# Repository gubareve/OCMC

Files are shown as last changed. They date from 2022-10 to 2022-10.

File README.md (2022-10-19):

# Open-source Custom Mechanical Keyboard

OCMC is a custom PCB running on the ATMEGA328P chipset.
Designed using KiCAD 6.0 and assembled using JLCPCB.






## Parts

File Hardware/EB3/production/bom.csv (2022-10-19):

Designator | Footprint | Quantity | Value | LCSC Part #
J2 | USB_C_Receptacle_XKB_U262-16XN-4BVC11 | 1 | USB_C_Receptacle
Y1 | Crystal_SMD_3225-4Pin_3.2x2.5mm | 1 | 16MHz | C13738
D1 | LED_0805_2012Metric | 1 | LED | C84256
C5 | C_0805_2012Metric | 1 | 10uF | C17024
JP3 | SolderJumper-2_P1.3mm_Open_RoundedPad1.0x1.5mm | 1 | SolderJumper_2_Open
J4 | PinSocket_1x03_P2.54mm_Vertical | 1 | Power Connectors
J3 | PinSocket_1x06_P2.54mm_Vertical | 1 | Programming Connectors
C2 | C_0805_2012Metric | 1 | 10uF | C17024
DS1 | WC1602A | 1 | WC1602A
SW3 | SW_Cherry_MX_Plate_1.00u | 1 | CONTROL
SW15 | SW_Cherry_MX_Plate_1.00u | 1 | 6
SW9 | SW_Cherry_MX_Plate_1.00u | 1 | 8
SW5 | SW_Cherry_MX_Plate_1.00u | 1 | 4
U1 | DIP-28_W7.62mm | 1 | ATmega328-P
JP5 | SolderJumper-2_P1.3mm_Open_RoundedPad1.0x1.5mm | 1 | SolderJumper_2_Open
RV1 | Potentiometer_Piher_PT-6-V_Vertical_Hole | 1 | 10k
R3 | R_0805_2012Metric | 1 | 10k | C17414
SW10 | SW_Cherry_MX_Plate_1.00u | 1 | 5
SW7 | SW_Cherry_MX_Plate_1.00u | 1 | ENTER
C3 | C_0805_2012Metric | 1 | 10uF | C17024
JP2 | TestPoint_2Pads_Pitch2.54mm_Drill0.8mm | 1 | 9-12v
SW12 | SW_Cherry_MX_Plate_1.00u | 1 | 0
SW19 | SW_Cherry_MX_Plate_1.00u | 1 | MULT
SW13 | SW_Cherry_MX_Plate_1.00u | 1 | DEL
JP4 | TestPoint_2Pads_Pitch2.54mm_Drill0.8mm | 1 | RESET
C4 | C_0805_2012Metric | 1 | 0.1uF | C49678
SW21 | SW_Cherry_MX_Plate_1.00u | 1 | SUB
J1 | BarrelJack_GCT_DCJ200-10-A_Horizontal | 1 | Barrel_Jack
SW20 | SW_Cherry_MX_Plate_1.00u | 1 | DIV
SW8 | SW_Cherry_MX_Plate_1.00u | 1 | ALT
C7 | C_0805_2012Metric | 1 | 100n | C49678
C6 | C_0805_2012Metric | 1 | 22pf | C1804
SW11 | SW_Cherry_MX_Plate_1.00u | 1 | 2
J5 | PinSocket_1x04_P2.54mm_Vertical | 1 | SPI Connectors
SW16 | SW_Cherry_MX_Plate_1.00u | 1 | 3
C1 | C_0805_2012Metric | 1 | 22pf | C1804
SW18 | SW_Cherry_MX_Plate_1.00u | 1 | CLR
SW4 | SW_Cherry_MX_Plate_1.00u | 1 | 7
SW6 | SW_Cherry_MX_Plate_1.00u | 1 | 1
SW1 | SW_Push_2P2T_Toggle_CK_PVA2OAH5xxxxxxV2 | 1 | SW_SPST
SW22 | SW_Cherry_MX_Plate_1.00u | 1 | ADD
R1 | R_0805_2012Metric | 1 | 50
SW17 | SW_Cherry_MX_Plate_1.00u | 1 | DOT
U2 | TO-92_Inline | 1 | L78L05_TO92
SW14 | SW_Cherry_MX_Plate_1.00u | 1 | 9
JP1 | TestPoint_2Pads_Pitch2.54mm_Drill0.8mm | 1 | 5v
R2 | R_0805_2012Metric | 1 | 220 | C17520

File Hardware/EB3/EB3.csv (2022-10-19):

Id | Designator | Package | Quantity | Designation | Supplier and ref
1 | J2 | USB_Micro-B_Amphenol_10118194_Horizontal | 1 | USB_B_Micro
2 | SW1 | SW_Push_2P2T_Toggle_CK_PVA2OAH5xxxxxxV2 | 1 | SW_SPST
3 | Y1 | C_1210_3225Metric | 1 | 16MHz
4 | U2 | TO-92_Inline | 1 | L78L05_TO92
5 | U1 | DIP-28_W7.62mm | 1 | ATmega328-P
6 | RV1 | Potentiometer_Piher_PT-6-V_Vertical_Hole | 1 | 10k
7 | R3 | R_0805_2012Metric | 1 | 10k
8 | R2 | R_0805_2012Metric | 1 | 220
9 | R1 | R_0805_2012Metric | 1 | 200
10 | JP5,JP3 | SolderJumper-2_P1.3mm_Open_RoundedPad1.0x1.5mm | 2 | SolderJumper_2_Open
11 | JP4 | TestPoint_2Pads_Pitch2.54mm_Drill0.8mm | 1 | RESET
12 | JP2 | TestPoint_2Pads_Pitch2.54mm_Drill0.8mm | 1 | 9-12v
13 | JP1 | TestPoint_2Pads_Pitch2.54mm_Drill0.8mm | 1 | 5v
14 | J5 | PinSocket_1x04_P2.54mm_Vertical | 1 | SPI Connectors
15 | J4 | PinSocket_1x03_P2.54mm_Vertical | 1 | Power Connectors
16 | J3 | PinSocket_1x06_P2.54mm_Vertical | 1 | Programming Connectors
17 | J1 | BarrelJack_GCT_DCJ200-10-A_Horizontal | 1 | Barrel_Jack
18 | D1 | LED_0805_2012Metric | 1 | LED
19 | C7 | C_0805_2012Metric | 1 | 100n
20 | C6,C1 | C_0805_2012Metric | 2 | 22pf
21 | C5,C3,C2 | C_0805_2012Metric | 3 | 10uF
22 | C4 | C_0805_2012Metric | 1 | 0.1uF
23 | DS1 | WC1602A | 1 | WC1602A
24 | SW3 | SW_Cherry_MX_Plate_1.00u | 1 | CONTROL
25 | SW15 | SW_Cherry_MX_Plate_1.00u | 1 | 6
26 | SW9 | SW_Cherry_MX_Plate_1.00u | 1 | 8
27 | SW5 | SW_Cherry_MX_Plate_1.00u | 1 | 4
28 | SW10 | SW_Cherry_MX_Plate_1.00u | 1 | 5
29 | SW7 | SW_Cherry_MX_Plate_1.00u | 1 | ENTER
30 | SW12 | SW_Cherry_MX_Plate_1.00u | 1 | 0
31 | SW19 | SW_Cherry_MX_Plate_1.00u | 1 | MULT
32 | SW13 | SW_Cherry_MX_Plate_1.00u | 1 | DEL
33 | SW21 | SW_Cherry_MX_Plate_1.00u | 1 | SUB
34 | SW20 | SW_Cherry_MX_Plate_1.00u | 1 | DIV
35 | SW8 | SW_Cherry_MX_Plate_1.00u | 1 | ALT
36 | SW11 | SW_Cherry_MX_Plate_1.00u | 1 | 2
37 | SW16 | SW_Cherry_MX_Plate_1.00u | 1 | 3
38 | SW18 | SW_Cherry_MX_Plate_1.00u | 1 | CLR
39 | SW4 | SW_Cherry_MX_Plate_1.00u | 1 | 7
40 | SW6 | SW_Cherry_MX_Plate_1.00u | 1 | 1
41 | SW22 | SW_Cherry_MX_Plate_1.00u | 1 | ADD
42 | SW17 | SW_Cherry_MX_Plate_1.00u | 1 | DOT
43 | SW14 | SW_Cherry_MX_Plate_1.00u | 1 | 9

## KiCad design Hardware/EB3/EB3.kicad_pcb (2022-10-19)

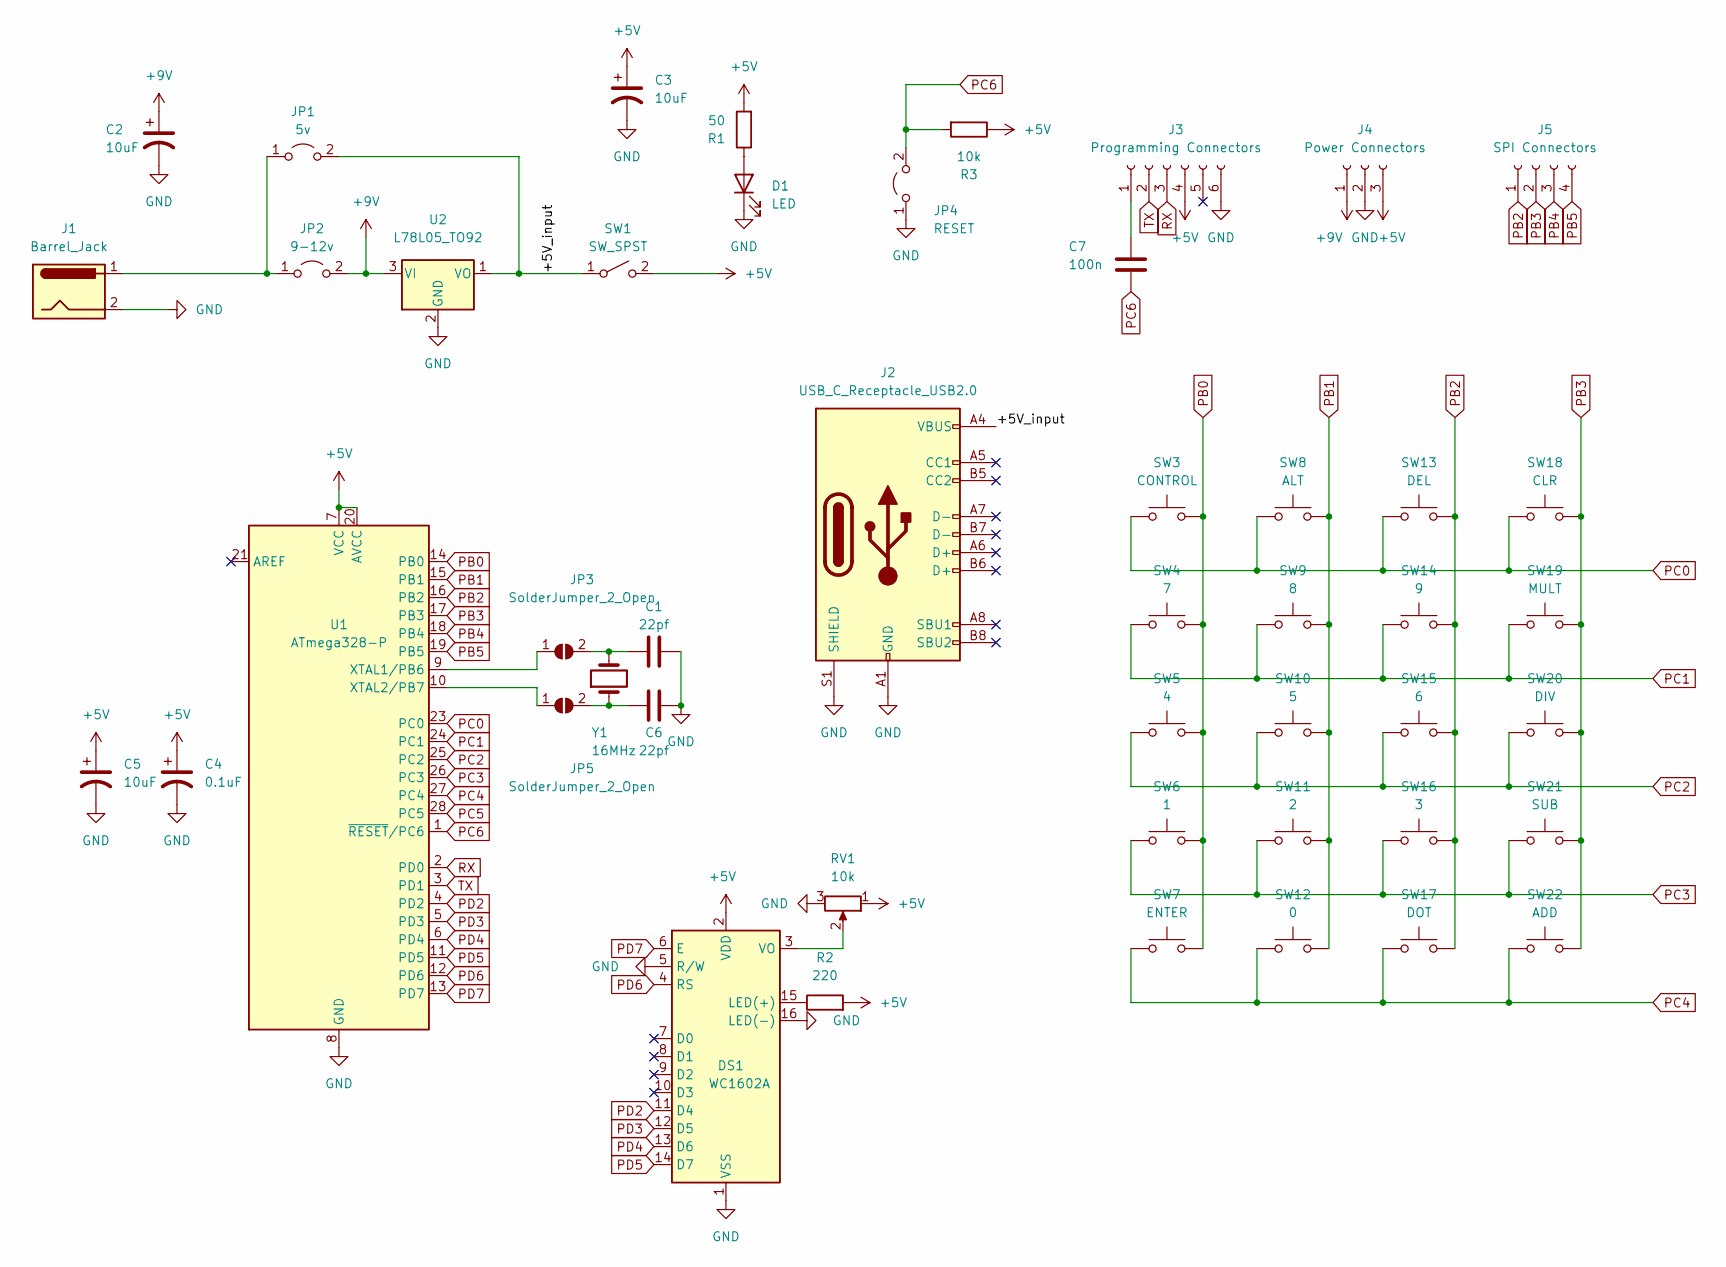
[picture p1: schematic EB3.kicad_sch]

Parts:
C1, C6: 22pf; C_0805_2012Metric; LCSC C1804
C2, C3, C5: 10uF; C_0805_2012Metric; LCSC C17024
C4: 0.1uF; C_0805_2012Metric; LCSC C49678
C7: 100n; C_0805_2012Metric; LCSC C49678
D1: LED; LED_0805_2012Metric; LCSC C84256
DS1: WC1602A
J1: Barrel_Jack; BarrelJack_GCT_DCJ200-10-A_Horizontal
J2: USB_C_Receptacle_USB2.0
J3: Programming Connectors; PinSocket_1x06_P2.54mm_Vertical
J4: Power Connectors; PinSocket_1x03_P2.54mm_Vertical
J5: SPI Connectors; PinSocket_1x04_P2.54mm_Vertical
JP1: 5v; TestPoint_2Pads_Pitch2.54mm_Drill0.8mm
JP2: 9-12v; TestPoint_2Pads_Pitch2.54mm_Drill0.8mm
JP3, JP5: SolderJumper_2_Open; SolderJumper-2_P1.3mm_Open_RoundedPad1.0x1.5mm
JP4: RESET; TestPoint_2Pads_Pitch2.54mm_Drill0.8mm
R1: 50; R_0805_2012Metric; LCSC C23182
R2: 220; R_0805_2012Metric; LCSC C17520
R3: 10k; R_0805_2012Metric; LCSC C17414
RV1: 10k; Potentiometer_Piher_PT-6-V_Vertical_Hole
SW1: SW_SPST; SW_Push_2P2T_Toggle_CK_PVA2OAH5xxxxxxV2
SW3: CONTROL; SW_Cherry_MX_Plate_1.00u
SW4: 7; SW_Cherry_MX_Plate_1.00u
SW5: 4; SW_Cherry_MX_Plate_1.00u
SW6: 1; SW_Cherry_MX_Plate_1.00u
SW7: ENTER; SW_Cherry_MX_Plate_1.00u
SW8: ALT; SW_Cherry_MX_Plate_1.00u
SW9: 8; SW_Cherry_MX_Plate_1.00u
SW10: 5; SW_Cherry_MX_Plate_1.00u
SW11: 2; SW_Cherry_MX_Plate_1.00u
SW12: 0; SW_Cherry_MX_Plate_1.00u
SW13: DEL; SW_Cherry_MX_Plate_1.00u
SW14: 9; SW_Cherry_MX_Plate_1.00u
SW15: 6; SW_Cherry_MX_Plate_1.00u
SW16: 3; SW_Cherry_MX_Plate_1.00u
SW17: DOT; SW_Cherry_MX_Plate_1.00u
SW18: CLR; SW_Cherry_MX_Plate_1.00u
SW19: MULT; SW_Cherry_MX_Plate_1.00u
SW20: DIV; SW_Cherry_MX_Plate_1.00u
SW21: SUB; SW_Cherry_MX_Plate_1.00u
SW22: ADD; SW_Cherry_MX_Plate_1.00u
U1: ATmega328-P; DIP-28_W7.62mm
U2: L78L05_TO92; TO-92_Inline
Y1: 16MHz; Crystal_SMD_3225-4Pin_3.2x2.5mm; LCSC C13738

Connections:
+5V: C3.1, C4.1, C5.1, DS1.2 (VDD), J3.4, J4.3, R1.2, R2.2, R3.1, RV1.1, SW1.2 (B), U1.7 (VCC), U1.20 (AVCC)
+9V: C2.1, J4.1, JP2.2 (B), U2.3 (VI)
/+5V_input: J2.A4 (VBUS), J2.A9 (VBUS), J2.B4 (VBUS), J2.B9 (VBUS), JP1.2 (B), SW1.1 (A), U2.1 (VO)
GND: C1.2, C2.2, C3.2, C4.2, C5.2, C6.2, D1.1 (K), DS1.1 (VSS), DS1.5 (R/W), DS1.16 (LED(-)), J1.2, J2.A1 (GND), J2.A12 (GND), J2.B1 (GND), J2.B12 (GND), J2.S1 (SHIELD), J3.6, J4.2, JP4.1 (A), RV1.3, U1.8 (GND), U1.22 (GND), U2.2 (GND), Y1.3
unnamed: C1.1, JP3.2 (B), Y1.2
unnamed: C6.1, JP5.2 (B), Y1.1
unnamed: C7.1, J3.1
unnamed: D1.2 (A), R1.1
unnamed: DS1.3 (VO), RV1.2
unnamed: DS1.15 (LED(+)), R2.1
unnamed: J1.1, JP1.1 (A), JP2.1 (A)
unnamed: JP3.1 (A), U1.9 (XTAL1/PB6)
unnamed: JP5.1 (A), U1.10 (XTAL2/PB7)
PB0: SW3.2, SW4.2, SW5.2, SW6.2, SW7.2, U1.14 (PB0)
PB1: SW8.2, SW9.2, SW10.2, SW11.2, SW12.2, U1.15 (PB1)
PB2: J5.1, SW13.2, SW14.2, SW15.2, SW16.2, SW17.2, U1.16 (PB2)
PB3: J5.2, SW18.2, SW19.2, SW20.2, SW21.2, SW22.2, U1.17 (PB3)
PB4: J5.3, U1.18 (PB4)
PB5: J5.4, U1.19 (PB5)
PC0: SW3.1, SW8.1, SW13.1, SW18.1, U1.23 (PC0)
PC1: SW4.1, SW9.1, SW14.1, SW19.1, U1.24 (PC1)
PC2: SW5.1, SW10.1, SW15.1, SW20.1, U1.25 (PC2)
PC3: SW6.1, SW11.1, SW16.1, SW21.1, U1.26 (PC3)
PC4: SW7.1, SW12.1, SW17.1, SW22.1, U1.27 (PC4)
PC5: U1.28 (PC5)
PC6: C7.2, JP4.2 (B), R3.2, U1.1 (~RESET/PC6)
PD2: DS1.11 (D4), U1.4 (PD2)
PD3: DS1.12 (D5), U1.5 (PD3)
PD4: DS1.13 (D6), U1.6 (PD4)
PD5: DS1.14 (D7), U1.11 (PD5)
PD6: DS1.4 (RS), U1.12 (PD6)
PD7: DS1.6 (E), U1.13 (PD7)
RX: J3.3, U1.2 (PD0)
TX: J3.2, U1.3 (PD1)

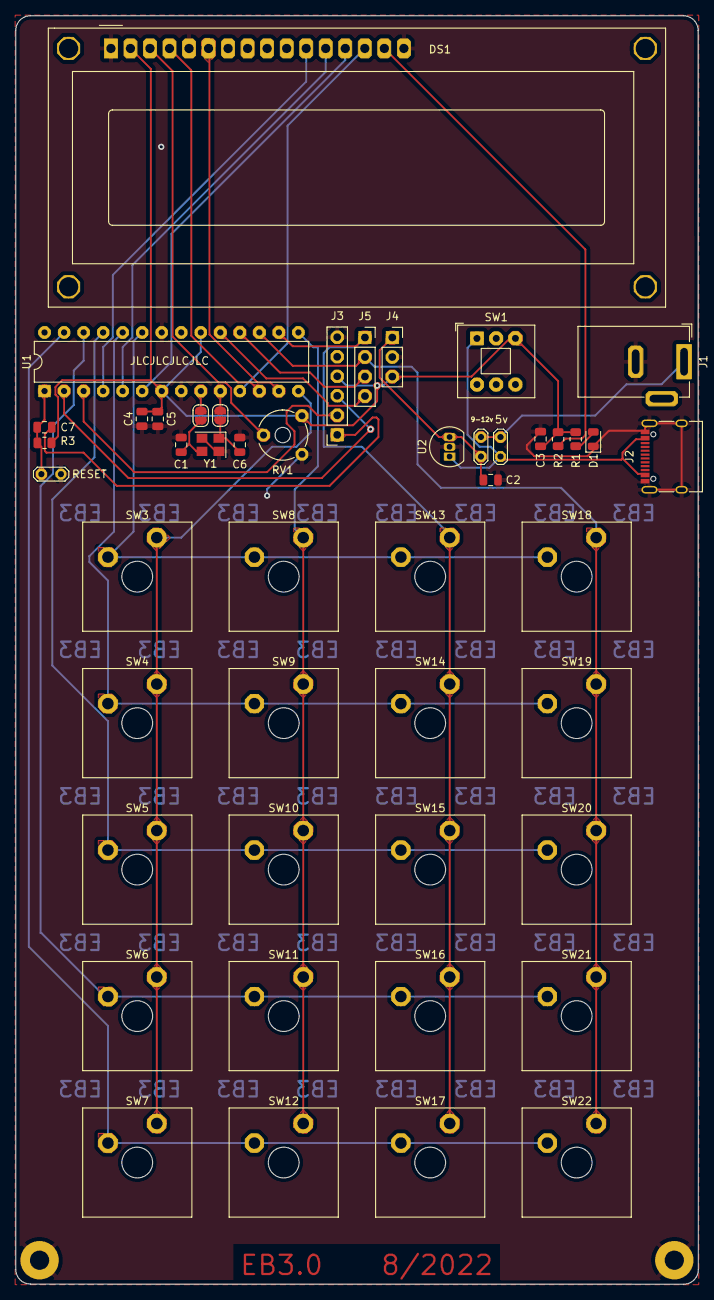
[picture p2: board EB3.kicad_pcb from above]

Board: 2 copper layers, 88.8 x 165.0 mm, 47 parts (0 on the bottom side), 33 nets.

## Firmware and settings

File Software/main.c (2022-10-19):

#include <LiquidCrystal.h>
#include "tinyexpr.h"

const int rs = 6, en = 7, d4 = 2, d5 = 3, d6 = 4, d7 = 5;

LiquidCrystal lcd(rs, en, d4, d5, d6, d7);


void setup() {:

  lcd.begin(16, 2);

  lcd.print("EB3 Calculator");
  lcd.setCursor(0, 1);
  lcd.print("By: Evan Gubarev");
  delay(3000);
  lcd.clear();
  lcd.print("Press any key.");

  pinMode(14, INPUT_PULLUP);
  pinMode(15, INPUT_PULLUP);
  pinMode(16, INPUT_PULLUP);
  pinMode(17, INPUT_PULLUP);
  pinMode(18, INPUT_PULLUP);
  pinMode(8, INPUT_PULLUP);
  pinMode(9, INPUT_PULLUP);
  pinMode(10, INPUT_PULLUP);
  pinMode(11, INPUT_PULLUP);



  Serial.begin(9600);
  Serial.println("Connection started");
  Serial.println(A0);
  Serial.println(PC0);
  Serial.println(PB0);
}

String eq = "";
String result = "";
const char layout[5][4] = { { 'a','^','(',')' }, { '7','8','9','/' }, { '4','5','6','*' }, { '1','2','3','-' }, { 'r','0','.','+' } };
char lastKeyPress = '\0';
int lastA = -1;


void loop() {

  int a=-1, b=-1;

  char charPressed;
  for (int i=0; i<4; i++) {
    pinMode(8+i, OUTPUT);
    digitalWrite(8+i, LOW);
    for (int j=0; j<5; j++) {
        if (digitalRead(14 + j) == LOW) {
          Serial.print(i);
          Serial.print(' ');
          Serial.println(j);
          a = i;
          b = j;
          break;
        }
    }
    if (lastA == i && b==-1) lastKeyPress = '\0';
    pinMode(8+i, INPUT_PULLUP);
  }


  delay(50);


  if (a==-1 || b==-1) return;

  char key = layout[b][a];
  if (lastKeyPress == key) return;
  lcd.clear();

  if (key != 'r' && key != 'a' && key != 's' && key != 'd' && key != 'f' ) {
  eq += (key);
  } else if (key == 'r') {
    eq.remove(eq.length()-1);
  } else if (key == 'a') {
    eq = "";
  }
  lastKeyPress = key;
  lastA = a;


  lcd.setCursor(0, 0);
  lcd.print(eq);
  lcd.setCursor(0, 1);
  int error;
  double result = te_interp(eq.c_str(), &error);
  if (error == 0) lcd.print(result);


}
